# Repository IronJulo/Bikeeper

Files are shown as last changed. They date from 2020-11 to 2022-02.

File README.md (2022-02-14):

# Bikeeper

## What is it? 💡
Bikeeper is a DUT 2 project. The goal of this project is to help bikers to find their motorbike and prevent motocycle stealing. In case off falling or stealing the arduino placed on the motorbike alert his owner. 

## Run 🚀
According to our documentation your can start this project by multiples ways.
### Manually 
You can manually start the Flask website. But we use docker for our database (MariaDB), openstreepmap tiles server, ngnix reverse proxy, grafana. All of this services can be started by executing some small script. 
For exemple : in docker folder run  `sh mariadb.sh` to install mariadb. 
All docker scripts look likes to this : 

```shell
docker run \
  --name bikeeperdb \
  -e=MYSQL_USER=teambikeeper \
  -e=MYSQL_PASSWORD=bikeeper \
  -e=MARIADB_RANDOM_ROOT_PASSWORD=no \
  -e=MYSQL_ROOT_PASSWORD=bikeepersu \
  -p 3306:3306 \
  -d mariadb/server:10.3 \
  --log-bin \
  --binlog-format=MIXED 
```
|Name | Script |Comments|
|--|--|--|
| MariaDB | docker/mariadb.sh | Simple Mariadb server to store flask website data.  |
| Grafana | docker/grafana/grafana.sh | Need few additionals steps: run `grafana-pluging.sh` to install plugings|
|TileServerGL|docker/openstreetmap/osm-server.sh||
|Ngnix|docker/ngnix/ngnix.sh|Reverse proxy to allow flask and grafana to iframe a chart (CORS issues)|

### Docker 🐳
Install docker and docker compose with `docker-setup.sh` script.
After run `docker-compose up` to start the project. 

## Documentation 📄 : 

To see our project documentation clone this repo and run  `docsify serve docs` or open [page](https://ironjulo.gitlab.io/project-bikeeper/#/)
We use [docsify](https://docsify.js.org/#/) to write this documentation. 
GitLab page : `https://ironjulo.gitlab.io/project-bikeeper/#/`

API is documented, in **docs** folder open `api-documentation.pdf`

## Screenshots 📸 





 
## 👷 Authors  :
| Name | Email|
|--|--|
| **Andrew Mary Huet de Barochez** | andrew.mary-huet-de-barochez@etu.univ-orleans.fr |
| **Jules Brossier** | jules.brss@gmail.com |
| **Xavier Lemaire**| xavier.lemaire@etu.univ-orleans.fr |
| **Kevin Talland**| kevin.talland@etu.univ-orleans.fr |
| **Dorian Hardy**|  [@thegostisdead]( https://github.com/thegostisdead ) |
| **Nicolas Pasquet**| nicolas.pasquet@etu.univ-orleans.fr |
| **Fabien Billauld**| fabien.billault@etu.univ-orleans.fr |
| **Mathieu Ramel**| mathieu.ramel@etu.univ-orleans.fr |

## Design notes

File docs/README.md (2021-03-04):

# Bikeeper

> Bikeeper is a project created at the IUT d'Orléans by 2nd year students

## Goals 

Bikeeper allows people with motorcycles to track their motorbike.     
When a user park his motorbike, bikeeper check the current GPS position of the device and send an alert to the user if a vibration or a suspicious behaviour is detected. 

## Doc

This documentation is not a user manual. This is a technical doc.

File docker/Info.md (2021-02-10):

# Info 

https://grafana.com/tutorials/run-grafana-behind-a-proxy/#1
https://grafana.com/docs/grafana/latest/administration/configure-docker/
https://stackoverflow.com/questions/47405597/x-frame-options-in-nginx-to-allow-all-domains
https://stackoverflow.com/questions/33111835/how-to-set-up-grafana-so-that-no-password-is-necessary-to-view-dashboards

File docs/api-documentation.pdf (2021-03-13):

# Bikeeper API

# Overview

Bikeeper API.

# Version information

Version : 1.0.0

# URI scheme

Host : bikeeperwebsite.com BasePath : /
Schemes : HTTP

# Paths

# Adds bikeeper to the database

POST /api/bikeeper/add/

### Description

This adds a new bikeeper device to the database.

### Responses

HTTP Code | Description | Schema
200 | OK | No Content

### Produces

- application/json

# Adds raw bikeeper to the database

POST /api/bikeeper/add_raw/

### Description

This adds a bikeeper with raw parameters to the database.

### Responses

HTTP Code | Description | Schema
200 | OK | No Content

### Produces

- application/json

# Gets current user contacts

GET /api/bikeeper/contacts/<string:device_id>/

### Description

This gets current user contacts from ORM and returns it.

### Responses

HTTP Code | Description | Schema
200 | OK | No Content

### Produces

- application/json

# Gets current user associated phone

GET /api/bikeeper/currentphone/<string:device_id>/

### Description

This gets the current user phone associated on the database from ORM and returns it.

### Responses

HTTP Code | Description | Schema
200 | OK | No Content

### Produces

- application/json

# Get current user picture stored in database

GET /api/bikeeper/get_battery_level/<string:device_id>

### Description

Get current user picture stored in database

### Responses

HTTP Code | Description | Schema
200 | OK | No Content

### Produces

- application/json

# Gets the device name of a given device

GET /api/bikeeper/get_bikeer_name_by_id/<string:device_id>

### Description

Gets the device name of a given device

### Responses

HTTP Code | Description | Schema
200 | OK | No Content

### Produces

- application/json

# Get last log that gives the location

GET /api/bikeeper/get_last_log_position/<string:device_id>

### Description

Get last log that gives the location

### Responses

HTTP Code | Description | Schema
200 | OK | No Content

### Produces

- application/json
Gets the user’s bikeepers that has logs at a given date.

GET /api/bikeeper/get_last_ride_bikeeper/<string:device_id>

### Description

Gets the user’s bikeepers that has logs at a given date.

### Responses

HTTP Code | Description | Schema
200 | OK | No Content

### Produces

- application/json

# Get logs corresponding to a date

GET /api/bikeeper/get_logs_at_date/<string:device_id>/<string:date>

### Description

Get logs corresponding to a date

### Responses

HTTP Code | Description | Schema
200 | OK | No Content

### Produces

- application/json

# Gets rides by user and selected date

GET /api/bikeeper/get_rides_bikeeper_from_user_at_time/<string:username>/<string:date>

### Description

Gets rides by user and selected date

### Responses

HTTP Code | Description | Schema
200 | OK | No Content

### Produces

- application/json
Gets a list of rides at a given date, bikeeper and user.

GET
/api/bikeeper/get_rides_from_user_at_time_with_bikeeper/<string:username>/<string:devi ce_id>/<string:date>

### Description

Gets a list of rides at a given date, bikeeper and user.

### Responses

HTTP Code | Description | Schema
200 | OK | No Content

### Produces

- application/json

# Gets bikeeper’s owner number

GET /api/bikeeper/get_user_num/<string:device_id>/

### Description

This gets the number of the bikeeper’s owner and returns it.

### Responses

HTTP Code | Description | Schema
200 | OK | No Content

### Produces

- application/json

# Removes selected device

DELETE /api/bikeeper/remove/<int:device_id>/

### Description

This removes the current device from the database using ORM function.

### Responses

HTTP Code | Description | Schema
200 | OK | No Content

### Produces

- application/json

# Get user research

GET /api/bikeeper/search_user/

### Description

Find user in database

### Responses

HTTP Code | Description | Schema
200 | OK | No Content

### Produces

- application/json

# Update current device settings to the database

POST /api/bikeeper/settings/<string:device_id>/update/

### Description

This updates settings of the device on the database using ORM function.

### Responses

HTTP Code | Description | Schema
200 | OK | No Content

### Produces

- application/json

# Get current contact picture stored in database

GET /api/contact/profile/<string:contact_id>

### Description

Get current contact picture stored in database

### Responses

HTTP Code | Description | Schema
200 | OK | No Content

### Produces

- application/json

# Get the current selected device stored in database

GET /api/current_device/<string:username>

### Description

Get the current selected device stored in database

### Responses

HTTP Code | Description | Schema
200 | OK | No Content

### Produces

- application/json

# Update the current selected device stored in database

GET /api/device/<int:id_device>

### Description

Update the current selected device stored in database

### Responses

HTTP Code | Description | Schema
200 | OK | No Content

### Produces

- application/json
This sends a SMS to the database.

POST /api/sms/add/

### Description

Sends sms to the bd

### Responses

HTTP Code | Description | Schema
200 | OK | No Content

### Produces

- application/json

# Gets current cpu usage

GET /api/stats/cpu/

### Description

This gets current cpu usage of the server.

### Responses

HTTP Code | Description | Schema
200 | OK | No Content

### Produces

- application/json

# Gets current ram usage

GET /api/stats/ram/

### Description

This gets current ram usage of the server.

### Responses

HTTP Code | Description | Schema
200 | OK | No Content

### Produces

- application/json

# Update the current selected device stored in database

POST /api/test/update_device/<string:username>/<int:id_device>

### Description

Update the current selected device stored in database

### Responses

HTTP Code | Description | Schema
200 | OK | No Content

### Produces

- application/json

# Get current user picture stored in database

GET /api/user/profile/<string:username>

### Description

Get current user picture stored in database

### Responses

HTTP Code | Description | Schema
200 | OK | No Content

### Produces

- application/json

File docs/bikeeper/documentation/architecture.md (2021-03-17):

# Architecture

>Global Arch

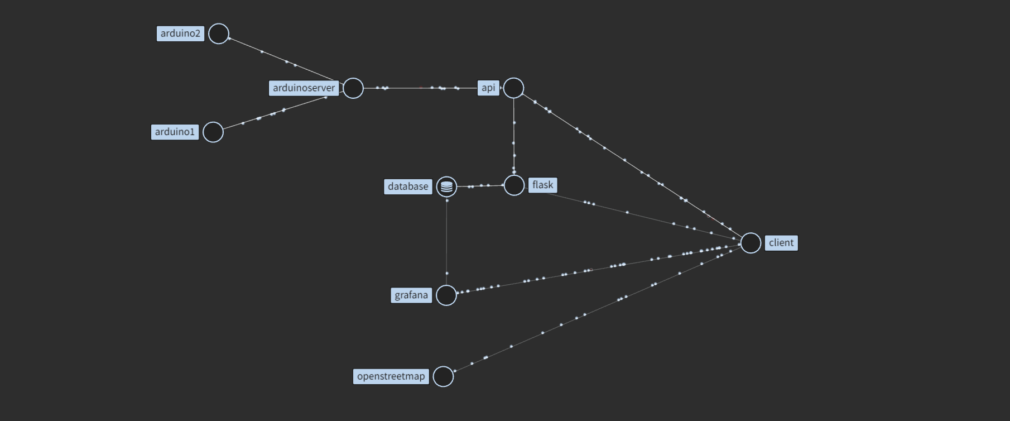
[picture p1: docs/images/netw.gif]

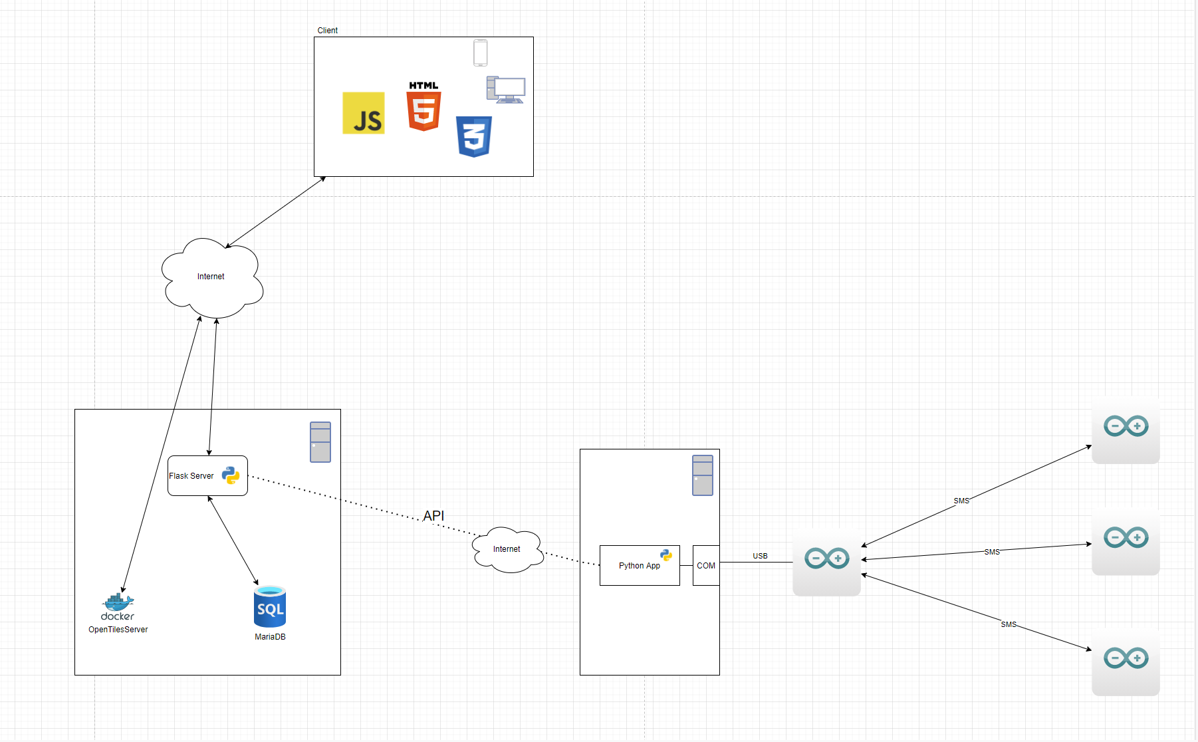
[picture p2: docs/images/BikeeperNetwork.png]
Bikeeper networks
    

>Website

Bikeeper website folders are organized in this way : 

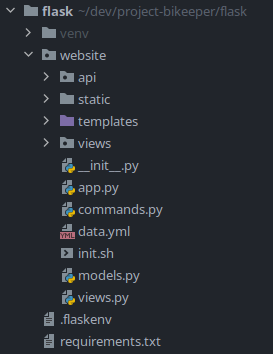
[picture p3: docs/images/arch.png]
Bikeeper arch


| Folder | What's inside ? | 
| --- |---|
| **api** |api to interact with bikeeper sms server using REST API |
| **static** | All assets files (images,css,js) |
|**templates** |All templates are inside. Bikeeper use 2 types of templates, mobile template and pc template.|
|**views** |All the views are bind to routes.|

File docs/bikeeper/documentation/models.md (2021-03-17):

# Models

> Database

We create this tables representation

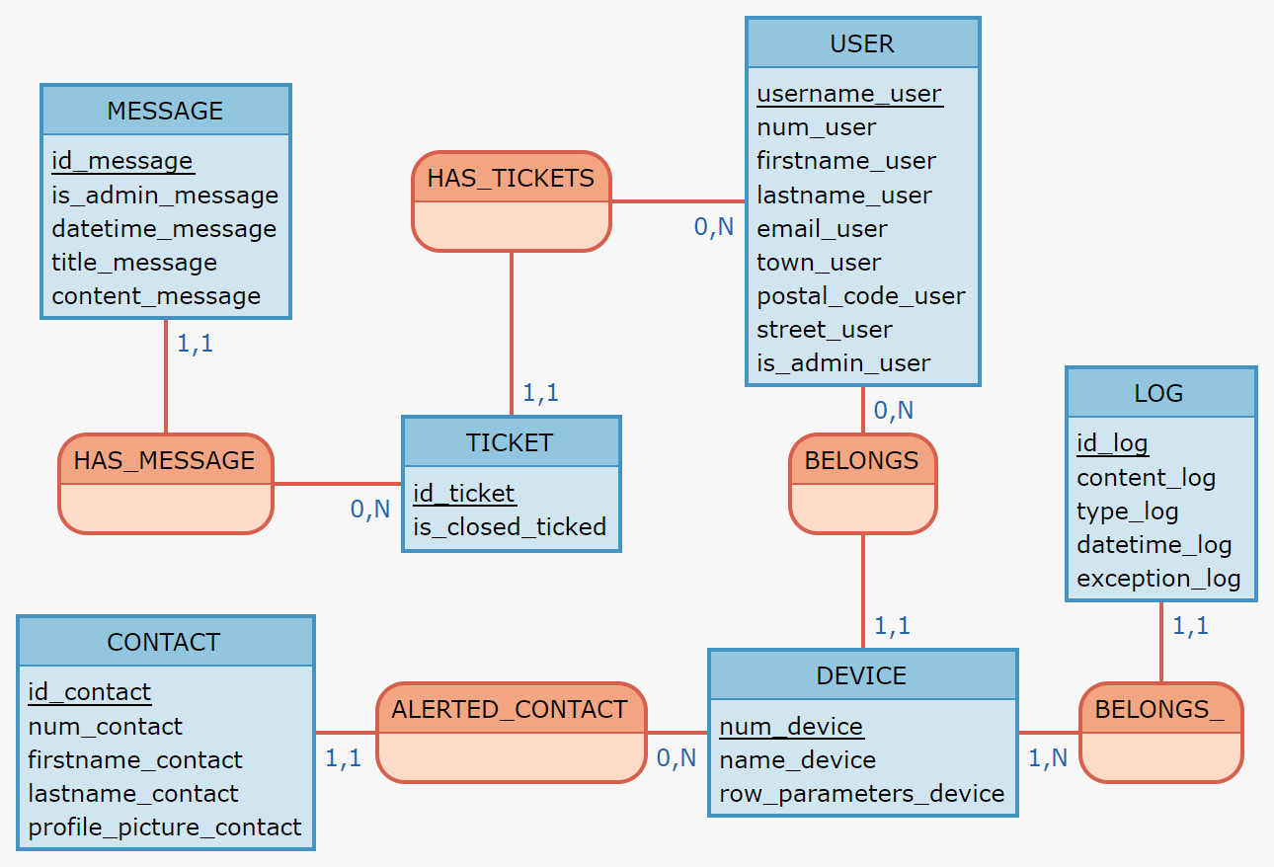
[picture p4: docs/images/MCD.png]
Bikeeper networks


---

> ORM

?> **Tip** To interact with our database we use [sqlalchemy](https://www.sqlalchemy.org/). 

Sqlalchemy provide a easy to use query system and a fast sql table creation. 

To call our database `app.py`
```python
app.config['SQLALCHEMY_DATABASE_URI'] = 'mysql+pymysql://{}:{}@{}/BIKEEPER'.format(os.environ.get('SERVER_USER'),os.environ.get('SERVER_PASSWORD'), os.environ.get('SERVER_IP'))

# Module that will build python objects
db = SQLAlchemy(app)

# Engine connecting to MariaDB
engine = sqlalchemy.create_engine(app.config['SQLALCHEMY_DATABASE_URI'], echo=False)  # , isolation_level="READ  

```

--- 

All tables are represented like this. 

```python 
class LOG(db.Model):
    """
    Store all activities generated by Bikeepers like Alerts, Moving etc...
    """
    id_log = db.Column(db.Integer, primary_key=True, autoincrement=True)
    content_log = db.Column(db.String(150))
    type_log = db.Column(db.String(20))
    datetime_log = db.Column(DateTime())
    exception_log = db.Column(db.String(160))
    num_device = db.Column(db.String(15), db.ForeignKey("DEVICE.num_device"))
    DEVICE = db.relationship("DEVICE", backref=db.backref("LOG", lazy="dynamic"))

    def __init__(self, content_log, type_log, datetime_log, exception_log, num_device):
        self.content_log = content_log
        self.type_log = type_log
        self.datetime_log = datetime_log
        self.exception_log = exception_log
        self.num_device = num_device

    def serialize(self):
        return {
            "id_log": self.id_log,
            "content_log": self.content_log,
            "type_log": self.type_log,
            "datetime_log": self.datetime_log,
            "exception_log": self.exception_log,
            "num_device": self.num_device
        }

```

?> **Tip** `serialize` method allow us to print directly the object. 

--- 

To make queries, we defined functions that return an Object defined in model class.

```python 
@staticmethod
    def get_last_message_by_ticket_id(ticket_id):
        """
        return: last message of the tickets
        """
        dict_message = ORM.get_message_by_ticket_id(ticket_id)
        if not dict_message:
            return {}
        return dict_message[max(dict_message.keys())]

    @staticmethod
    def messages_to_json(messages):
        """
        Turn the given messages into a json form
        """
        return jsonify(messages)

    @staticmethod
    def get_open_ticket():
        """
        :return: opened tickets,
        """
        res = session.query(TICKET).filter(TICKET.is_closed_ticket == 0).all()
        db.session.commit()
        return res
```

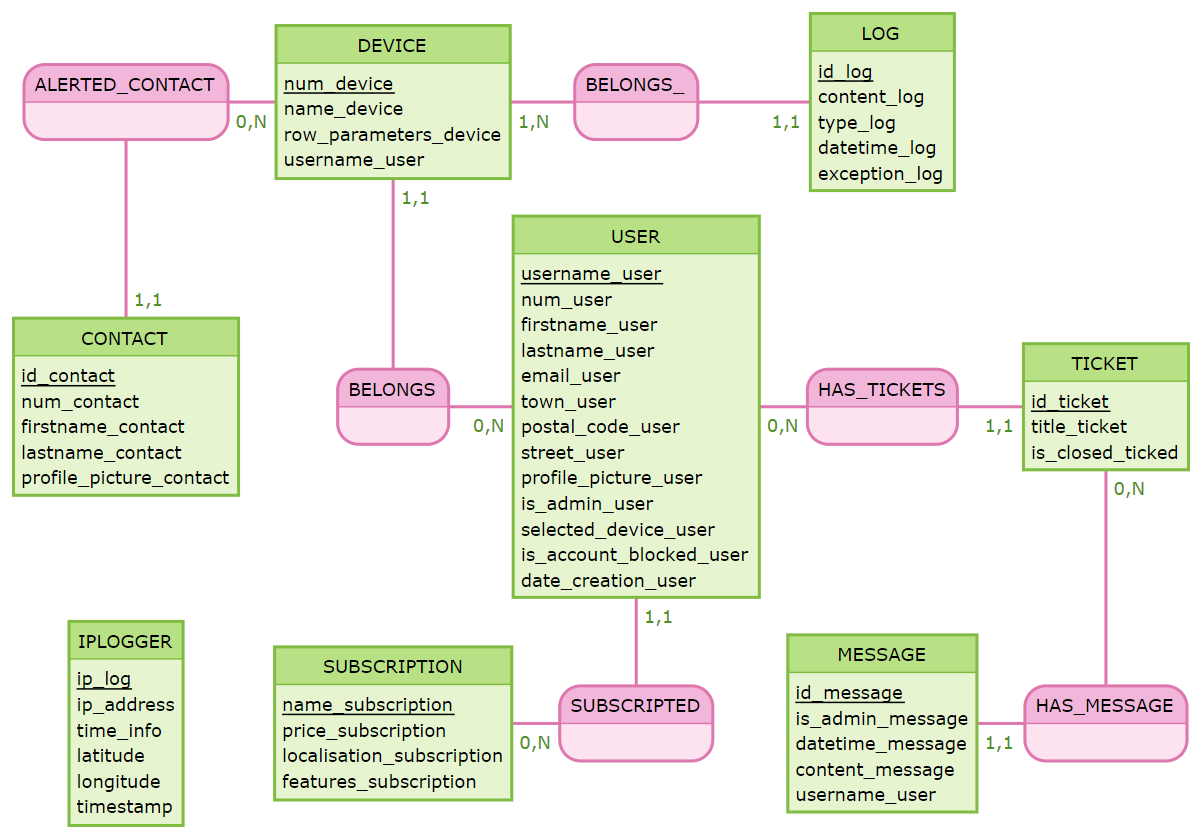
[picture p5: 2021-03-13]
bd/MCD.png

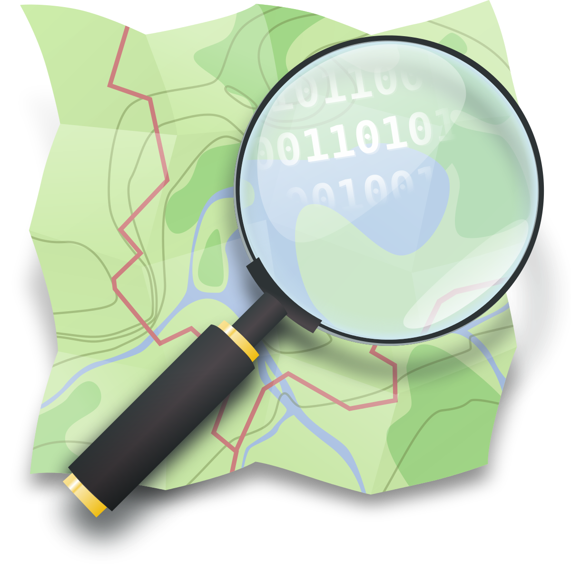
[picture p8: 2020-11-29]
flask/website/static/pc/assets/localisation-1.png

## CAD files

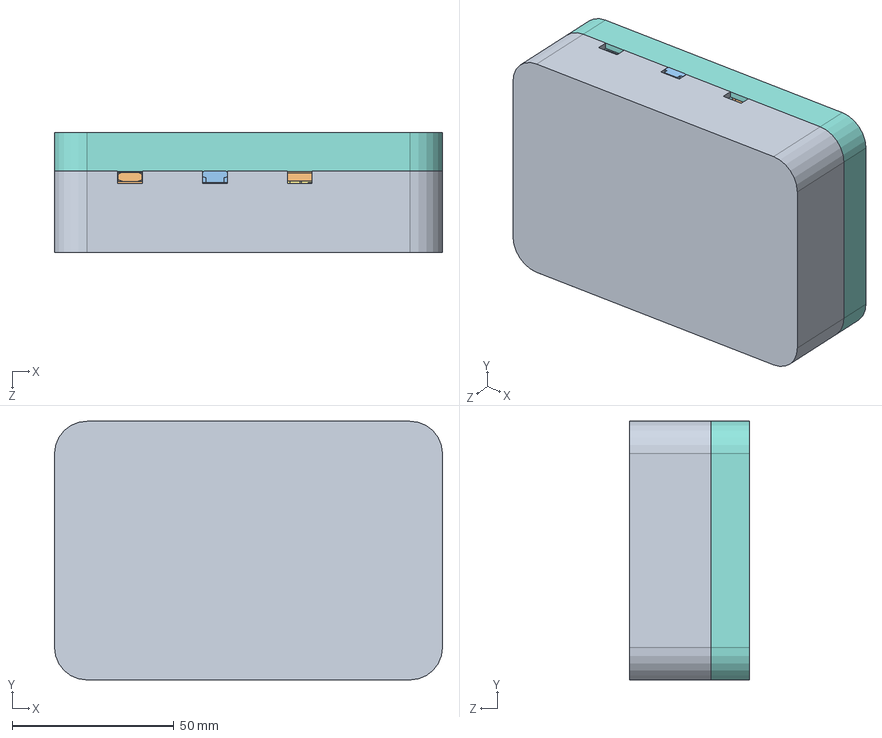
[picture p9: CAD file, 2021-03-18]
3D_Models/Build_Complete.SLDASM
120.0 x 80.0 x 37.1 mm
Pcb
Support_6x x 4
Support_15x x 2
Support_4x
Support_8x
Support_5x
Support_7x
Connector_2x x 2
Box_Bottom
Chargeur_Li-ion x 2
Arduino_Nano
Batterie
Tilt_Sensor
GPS
SIM_800L
Box_top

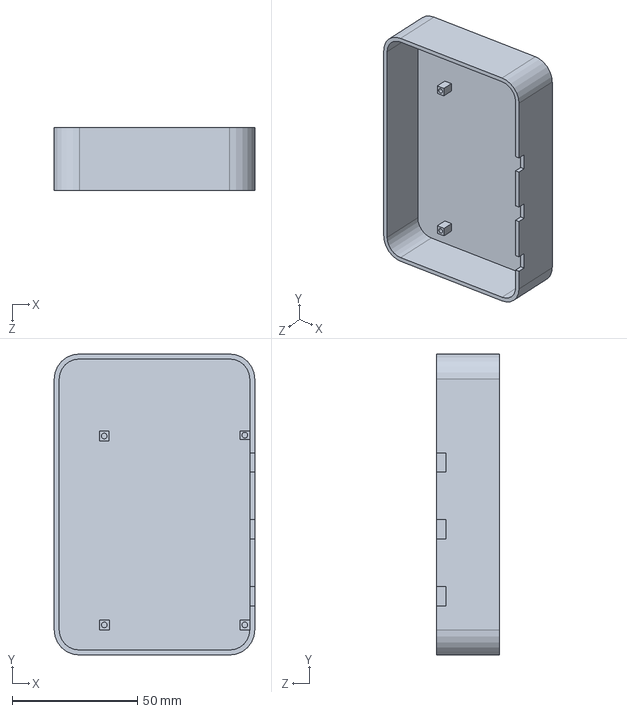
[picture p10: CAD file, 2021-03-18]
3D_Models/Complete_Build.SLDASM
80.0 x 120.0 x 25.2 mm

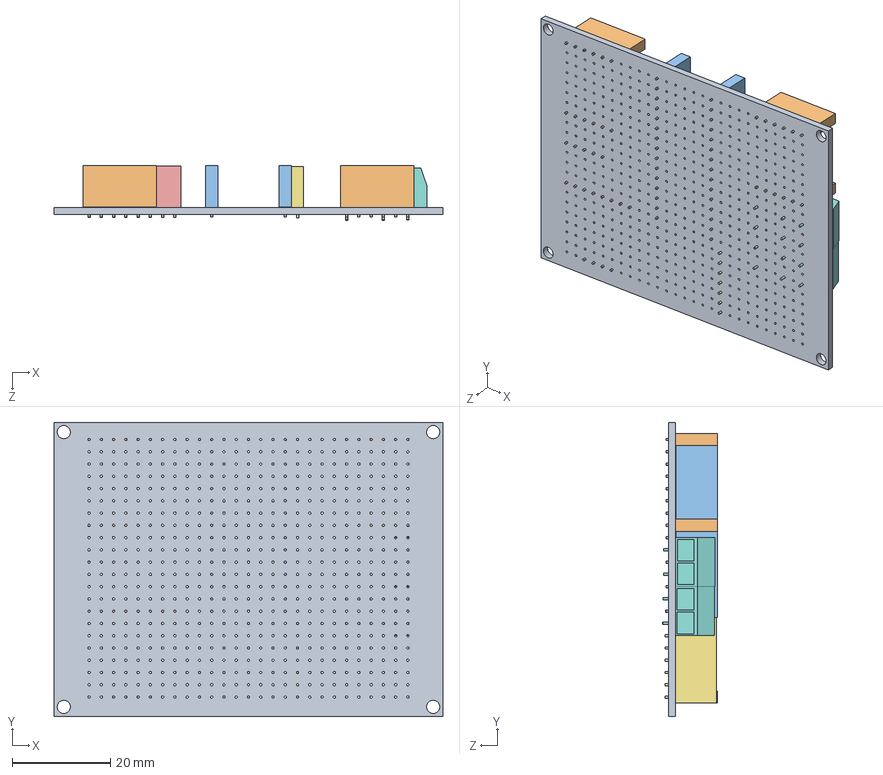
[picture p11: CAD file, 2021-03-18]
3D_Models/Build.SLDASM
79.3 x 60.0 x 11.2 mm
Pcb
Support_6x x 4
Support_15x x 2
Support_4x
Support_8x
Support_5x
Support_7x
Connector_2x x 2
Resistor x 4

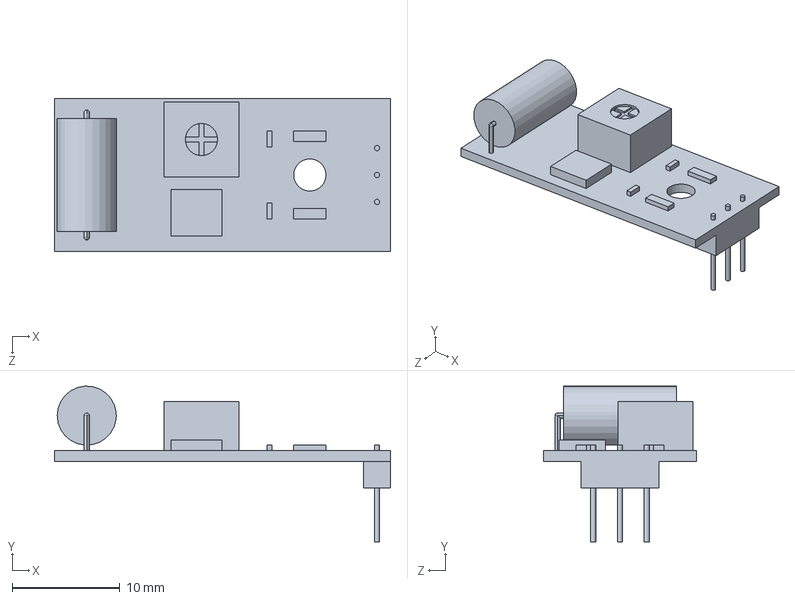
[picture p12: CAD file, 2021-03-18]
3D_Models/Vibration_detector.SLDPRT
31.2 x 14.5 x 14.2 mm

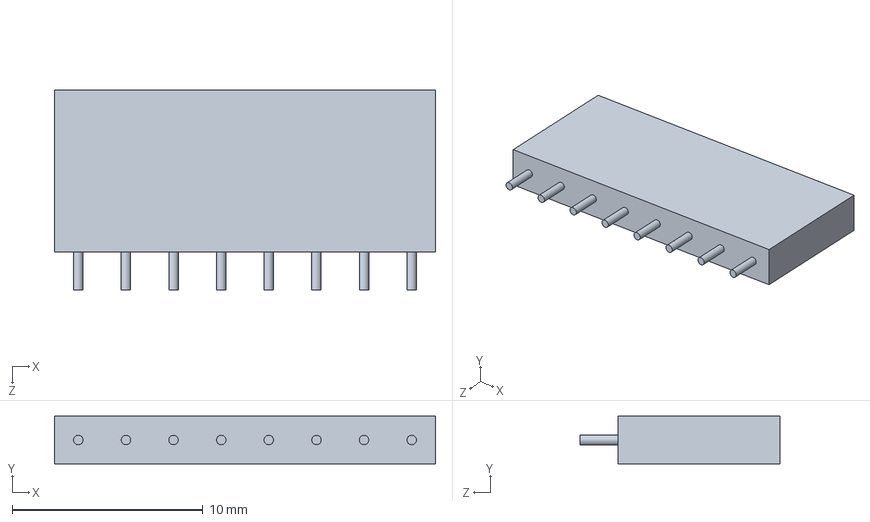
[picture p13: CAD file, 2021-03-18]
3D_Models/Support_8x.SLDPRT
20.0 x 2.50 x 10.5 mm

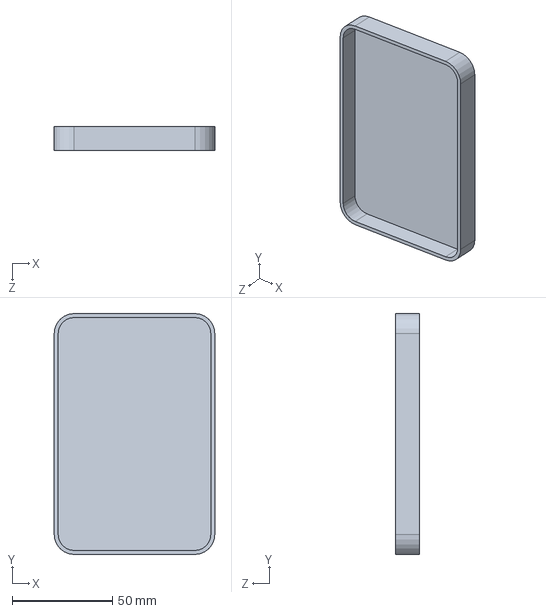
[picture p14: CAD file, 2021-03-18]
3D_Models/Box_top.SLDPRT
80.0 x 120.0 x 12.0 mm

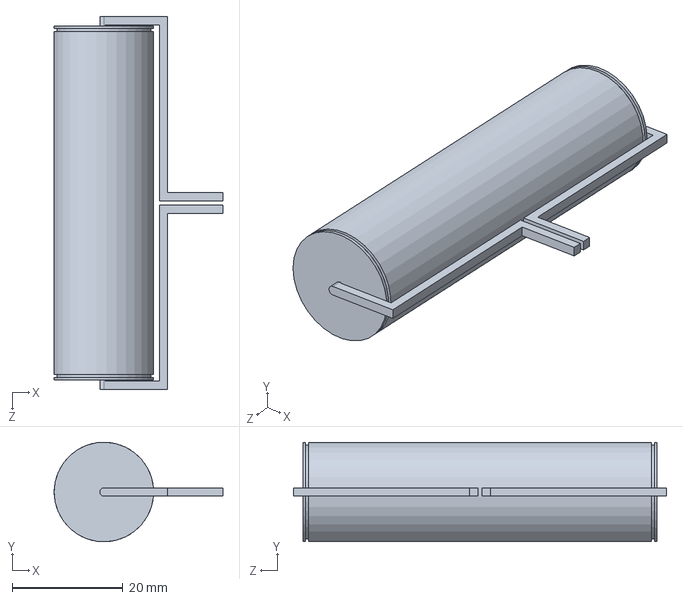
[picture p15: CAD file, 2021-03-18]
3D_Models/Batterie.SLDPRT
30.5 x 18.0 x 67.4 mm

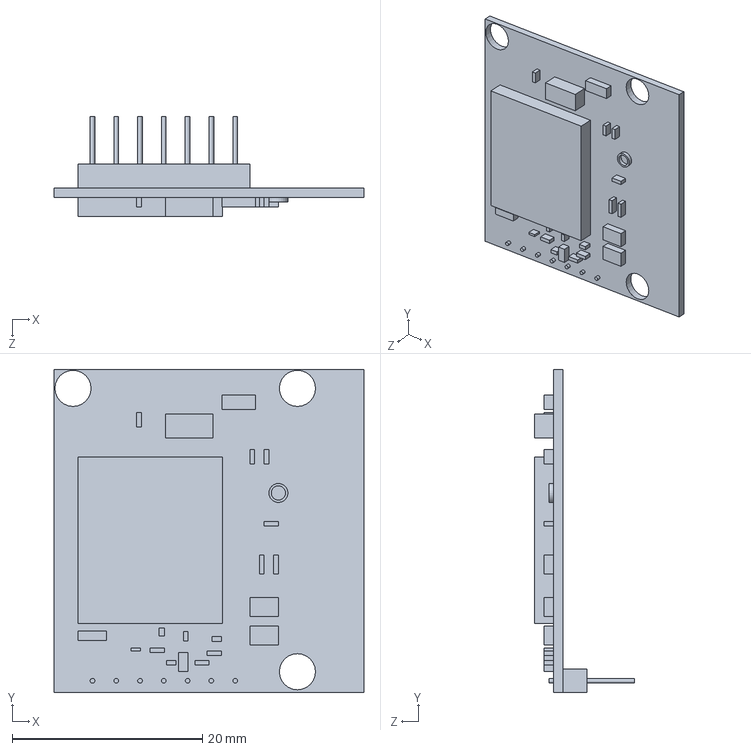
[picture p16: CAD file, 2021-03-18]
3D_Models/SIM_800L.SLDPRT
32.6 x 34.0 x 10.5 mm

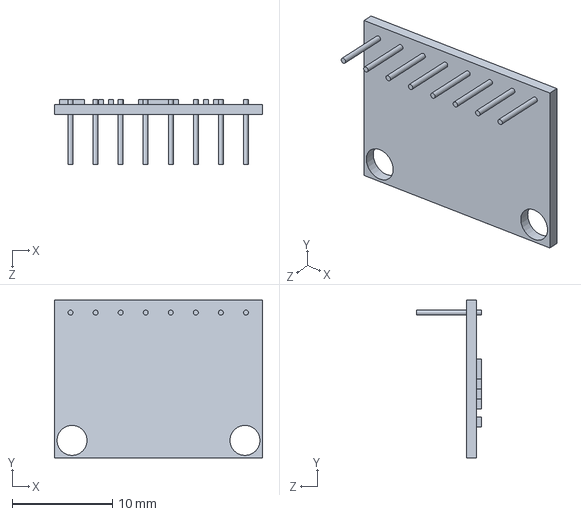
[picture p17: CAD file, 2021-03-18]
3D_Models/Tilt_Sensor.SLDPRT
20.8 x 15.8 x 6.50 mm

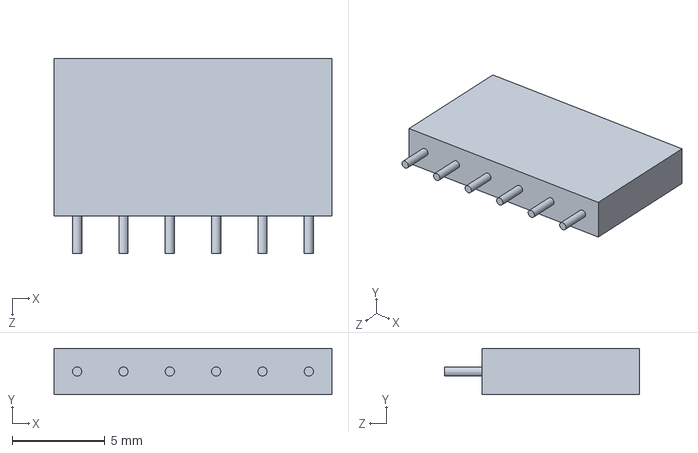
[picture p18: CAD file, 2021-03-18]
3D_Models/Support_6x.SLDPRT
15.0 x 2.50 x 10.5 mm

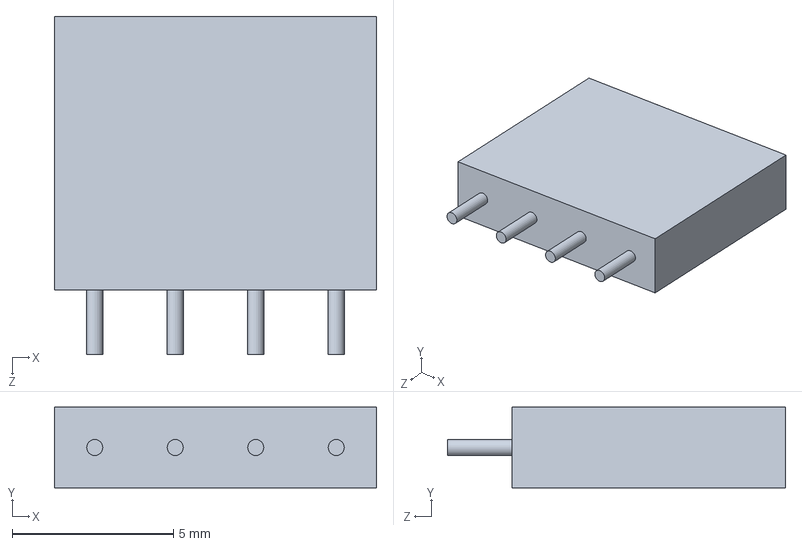
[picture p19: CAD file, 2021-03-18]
3D_Models/Support_4x.SLDPRT
10.0 x 2.50 x 10.5 mm

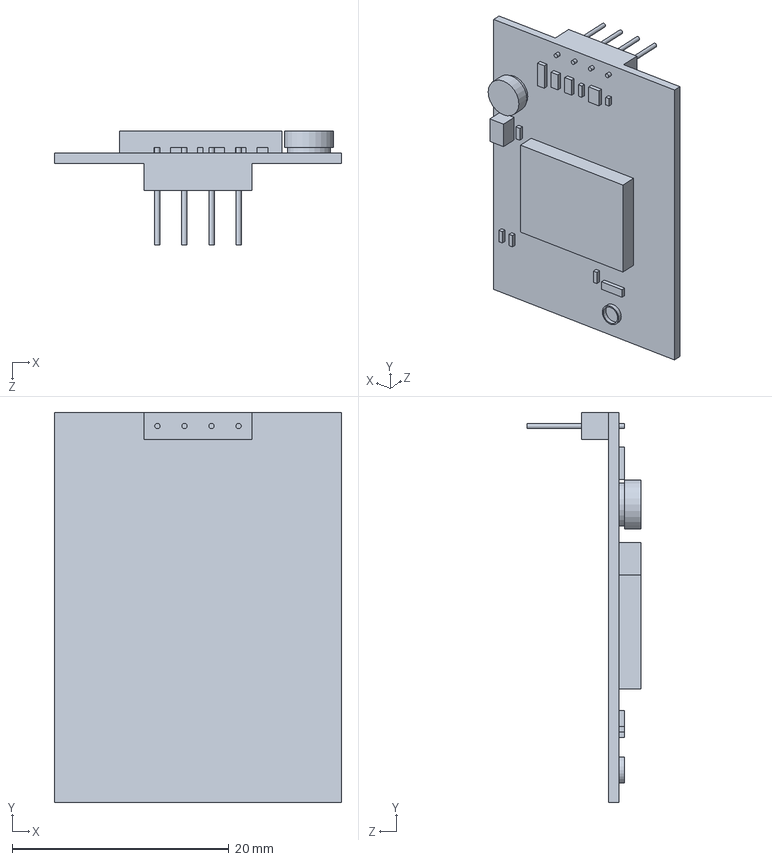
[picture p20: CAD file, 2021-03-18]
3D_Models/GPS.SLDPRT
26.5 x 36.0 x 10.5 mm

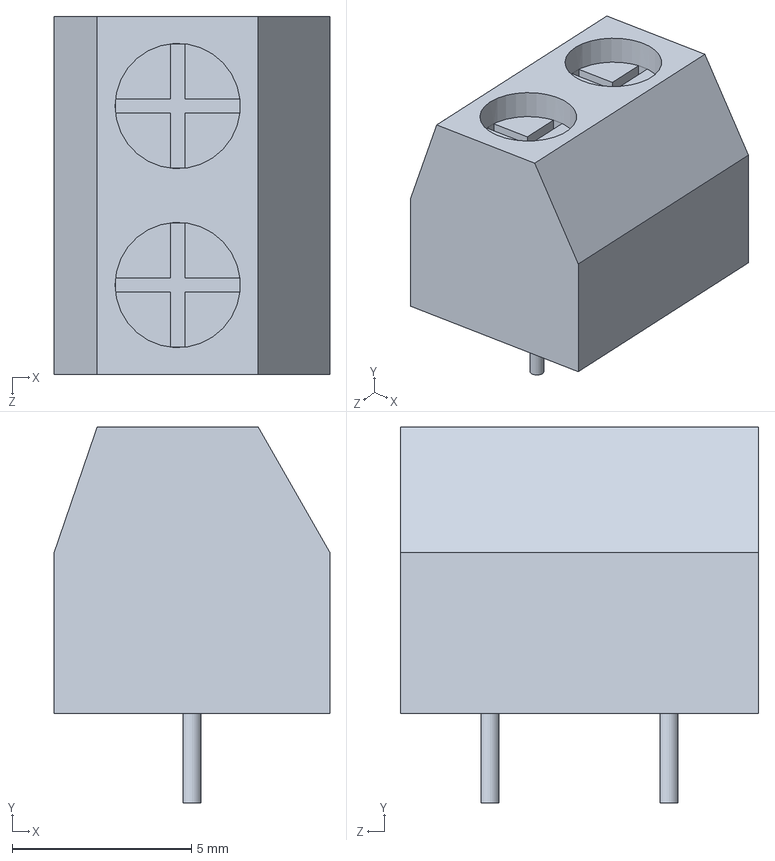
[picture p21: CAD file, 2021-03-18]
3D_Models/Connector_2x.SLDPRT
7.70 x 10.5 x 10.0 mm

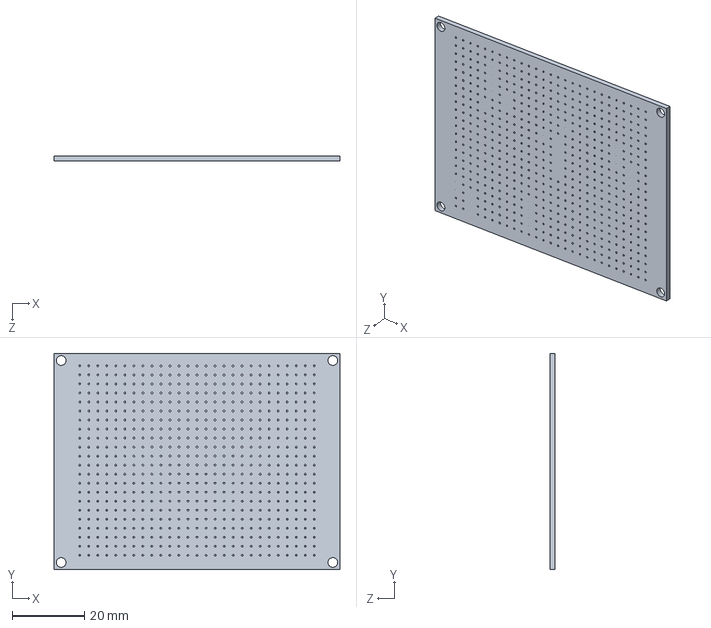
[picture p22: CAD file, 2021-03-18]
3D_Models/Pcb.SLDPRT
79.3 x 60.0 x 1.50 mm

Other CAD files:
3D_Models/Box_Bottom.SLDPRT
3D_Models/Support_7x.SLDPRT
3D_Models/Arduino_Nano.SLDPRT
3D_Models/Support_5x.SLDPRT
3D_Models/Build_Complete - Copie.SLDASM
3D_Models/Chargeur_Li-ion.SLDPRT
3D_Models/Resistor.SLDPRT
3D_Models/Support_15x.SLDPRT

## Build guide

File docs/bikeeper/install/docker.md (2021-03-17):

# Docker 

## How to start ?    

To run all services clone the repo and run `docker-compose up` .     
To stop the services type `docker-compose down` or press `ctrl+c` if your terminal is atteched to docker-compose.

## How it works ?  

Docker-compose will automatically deploy the bikeeper platform.     
It start : 
- mariadb
- grafana 
- ngnix
- flask
- openstreetmap

!> **Important** Please, replace the osm token by a new one. The token is available for one hour.  [Token](https://data.maptiler.com/downloads/tileset/osm/europe/france/centre/?wizard).   

```yaml
version: '3'
services:
  db:
    image: mariadb/server:10.3
    container_name: bikeeperbd
    expose:
      - 3306
    ports:
    - 3306:3306
    command:
      --log-bin
      --binlog-format=MIXED
    environment:
      - MYSQL_USER=teambikeeper
      - MYSQL_PASSWORD=bikeeper
      - MARIADB_RANDOM_ROOT_PASSWORD=no
      - MYSQL_ROOT_PASSWORD=bikeepersu
      - MYSQL_DATABASE=BIKEEPER
    healthcheck:
      test: "/usr/bin/mysql --user=teambikeeper --password=bikeeper --execute \"SHOW DATABASES;\""
      interval: 2s
      timeout: 20s
      retries: 10

  bikeeper-website:
    container_name: bikeeper
    depends_on:
      db:
        condition: service_healthy
    build: ./flask/
    volumes:
      - ./flask/:/usr/src/app/
    ports:
      - 8080:8080
    environment:
      PORT: 8080
      HOST: 0.0.0.0
      FLASK_DEBUG: 1

  osm:
    image: osm-bundle
    container_name: osm
    build:
      context: .
      dockerfile: ./docker/openstreetmap/osm.Dockerfile
      args:
        - MAP_TOKEN=WyJiZmZkZmM5NS1lMTVlLTRmYjgtYWFkZC1lNzM5MGQ1NjAxOTciLCItMSIsODcwMl0.YD6sPw.MEJHhB0BwjOEbCH95mX5o305m3s # get a new on here https://data.maptiler.com/downloads/tileset/osm/europe/france/centre/?wizard
    depends_on:
      db:
        condition: service_healthy
#    volumes:
#      - ./docker/openstreetmap/:/data
    ports:
      - 8989:80
    command:
      --bind 0.0.0.0
      --mbtiles /bundle/centre.mbtiles

  reverse-proxy:
    image: nginx
    container_name: nginxreverse
    depends_on:
      - grafana
      - bikeeper-website
    volumes:
      - ./docker/ngnix/nginx.conf:/etc/nginx/nginx.conf
    ports:
      - 80:80

  grafana:
    image: grafana/grafana
    container_name: grafana
    depends_on:
      - db
    environment:
      - "GF_INSTALL_PLUGINS=grafana-worldmap-panel"
      - "GF_INSTALL_IMAGE_RENDERER_PLUGIN=true"
      - "GF_DATABASE_TYPE=mysql"
      - "GF_DATABASE_NAME=BIKEEPER"
      - "GF_DATABASE_USER=teambikeeper"
      - "GF_DATABASE_HOST=db"
      - "GF_DATABASE_PASSWORD=bikeeper"
      - "GF_ANALYTICS_REPORTING_ENABLED=false"
      - "GF_SECURITY_ADMIN_USER=admin"
      - "GF_SECURITY_ADMIN_PASSWORD:=admin"
    volumes:
      - ./docker/grafana/grafana.ini:/etc/grafana/grafana.ini
      - ./docker/grafana/grafana-storage:/var/lib/grafana
    ports:
      - 3000:3000

```

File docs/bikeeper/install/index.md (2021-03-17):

# Installation 

?> **Tip** There is 2 ways to install Bikeeper. 

## By hands 

!> **Important** If you choose this method you need to install by our own **MariaDB, Grafana, Ngnix (reverse proxy for grafana), OpenStreetMap Server Tiles**

?> **Tips** In the project repository in the docker folder some shell scripts can help you to install all required services.

## With docker  

You can use our docker-compose file. 

?> **Tips**  This script will install docker and docker-compose. Run it with sudo. Tested on ubuntu ✅ 
```shell
apt update 
apt upgrade -y 
apt install apt-transport-https ca-certificates curl gnupg-agent software-properties-common -y 
curl -fsSL https://download.docker.com/linux/ubuntu/gpg | sudo apt-key add -
add-apt-repository "deb [arch=amd64] https://download.docker.com/linux/ubuntu $(lsb_release -cs) stable"
apt get update
apt get install docker-ce docker-ce-cli containerd.io -y 
usermod -aG docker $USER
# install docker compose after
curl -L "https://github.com/docker/compose/releases/download/1.28.4/docker-compose-$(uname -s)-$(uname -m)" -o /usr/local/bin/docker-compose
chmod +x /usr/local/bin/docker-compose
```

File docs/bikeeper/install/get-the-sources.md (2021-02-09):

# Get the sources

To get sources clone the last version of [Bikeeper repository](https://gitlab.com/IronJulo/project-bikeeper) 

```bash
git clone https://gitlab.com/IronJulo/project-bikeeper    

cd project-bikeeper
```

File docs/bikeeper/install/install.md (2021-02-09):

# Install & dependency

This project use many librairies. Bikeeper use virtualenv. 
Open project folder 

```bash
cd project-bikeeper/flask
```

Create python virtual env to install pip modules. 

```bash
python -m venv venv 
source venv/bin/activate
pip install -r requirements.txt
```

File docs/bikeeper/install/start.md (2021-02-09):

# Start !

```bash
cd project-bikeeper/flask/website    
flask run --host="0.0.0.0"
```

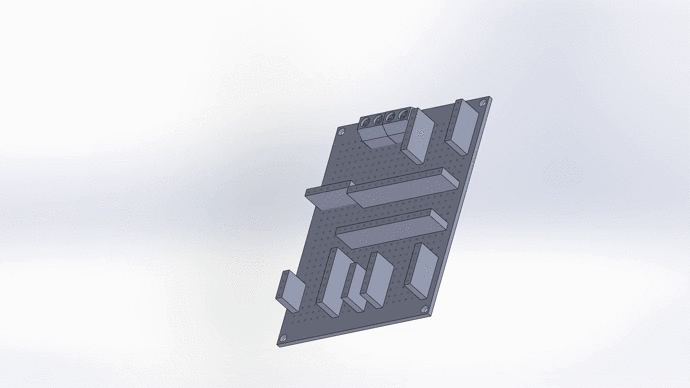
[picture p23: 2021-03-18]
3D_Models/Build_Complete5.gif

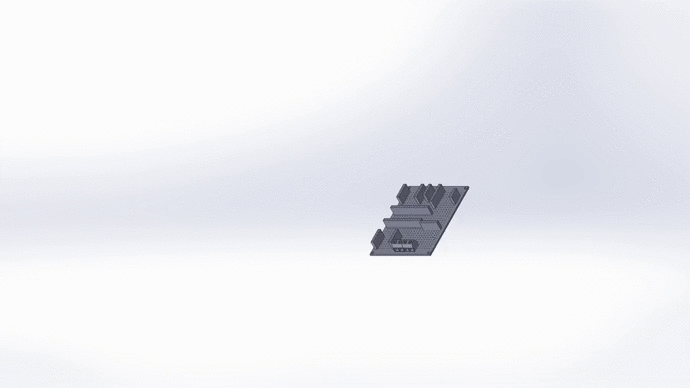
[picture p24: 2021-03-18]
3D_Models/Build_Complete4 (1).gif

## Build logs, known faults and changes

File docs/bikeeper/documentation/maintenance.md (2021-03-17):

# Maintenance

Maintain is very easy, just update ! 

To maintain bikeeper : 
- update your linux (`apt update -y && apt upgrade -y`)
- update docker image to lasted
- inspect logs (`docker logs container_name`)
- monitor your disk free space `df -h /` and `df -h | awk '{print $5 " " $6}' | sort -n | tail -5`
- Clean log ```for I in `ls "/var/log/*.log"`;do >"$I";done```
- Check internet connectivity `ping 8.8.8.8`
- Inspect Process performances `htop`   
If you have any issues email a Bikeeper developpers.

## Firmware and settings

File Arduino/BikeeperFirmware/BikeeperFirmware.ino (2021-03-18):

/*
for the arduino uno
                                             ╔═══╗                   ╔═════╗
                                        ╔════╣PWR╠═══════════════════╣ USB ╠══╗
                                        ║    ╚═══╝                   ╚═════╝  ║
                                        ║         GND/RST2  [ ][ ]            ║
                                        ║       MOSI2/SCK2  [ ][ ]  A5/SCL[ ] ║ 
                                        ║          5V/MISO2 [ ][ ]  A4/SDA[ ] ║
                                        ║                             AREF[ ] ║
                                        ║                              GND[ ] ║
                                        ║ [ ]N/C                    SCK/13[ ] ║
                                        ║ [ ]IOREF                 MISO/12[ ] ║
                                        ║ [ ]RESET                 MOSI/11[ ]~║
                                        ║ [ ]3V3    ╔═══╗               10[ ]~║
  +5V (2A) external power supply <══════║ [ ]5v    ═╣ A ╠═               9[ ]~║
    Ground external power supply <══════║ [ ]GND   ═╣ R ╠═               8[ ] ║══════> SIM800L rx 
                                        ║ [ ]GND   ═╣ D ╠═                    ║
                                        ║ [ ]Vin   ═╣ U ╠═               7[ ] ║══════> SIM800L tx
                                        ║          ═╣ I ╠═               6[ ]~║
                                        ║ [ ]A0    ═╣ N ╠═               5[ ]~║
                                        ║ [ ]A1    ═╣ O ╠═               4[ ] ║══════> GPS tx
                    Bike battery <══════║ [ ]A2     ╚═══╝           INT1/3[ ]~║
                  Device battery <══════║ [ ]A3                     INT0/2[ ] ║══════> Interrupt pin for the "do" pin of the vibration sensor
                   Gyroscope SDA <══════║ [ ]A4/SDA  RST SCK MISO     TX>1[ ] ║
                   Gyroscope SCL <══════║ [ ]A5/SCL  [ ] [ ] [ ]      RX<0[ ] ║
                                        ║            [ ] [ ] [ ]              ║
                                        ║            GND MOSI 5V ╔════════════╝
                                        ╚═══UNO_R3═══════════════╝ 
*/

#include <Arduino.h>
#include <TinyGPS++.h>
#include <SoftwareSerial.h> // for Sim800L & Tinygps++
#include <string.h>
#include "Wire.h"

#include "I_Sim800L.hpp"
#include "StringBuffer.hpp"
#include "StringsSms.hpp"
#include "SmsFormatter.hpp"
#include "Utils.hpp"

/*#include "Headers/messageHeader.h"
#include "Headers/messageAlert.h"
#include "Headers/messageTrajet.h"
#include "Headers/messageHeartbeat.h"
#include "Headers/messageReceived.h"*/
#include "Headers/location.h"

/* Sim800L */
// and +33664277796
#define SERVER_PHONE_NUMBER "+33664277796" // BiKServer number (main server) called to get user number

char userPhoneNumber[13] = "";

#define GSM_BAUDRATE 9600
#define GSM_RX 7
#define GSM_TX 8

SoftwareSerial softwareSim800l(GSM_RX, GSM_TX);

char sms_storage[150];
StringBuffer sms_buffer(sms_storage, sizeof(sms_storage));

char message_storage[80];
StringBuffer message_buffer(message_storage, sizeof(message_storage));
SmsFormatter smsFormatter(&message_buffer); //Not used all the time but to simplify sms generation

I_Sim800L sim800L(&softwareSim800l, &sms_buffer);
/* Sim800L */

/* States */
bool parked = false;
bool journey = false;
/* States */

/* Vibration sensor */
bool vibartion = false; // False most of the time but true if the module detected a vibration (trough interrupt)
#define VIBRATION 'V'
/* Vibration sensor */

/* Battery sensor */
#define DEVICE_BATTERY_PIN A3 // Declare the device battery (analog)
#define BIKE_BATTERY_PIN A2	 // Declare the device battery (analog)

#define deviceMaxBatteryVoltage 1024 //verify later
#define bikeMaxBatteryVoltage 1024 // verify later

double deviceBatteryLevel = 0;
double bikeBatteryLevel = 0;

bool isBatteryCharging = false;
/* Battery sensor */

/* GPS */
#define GPS_RX 4 // Declare the SIM800L onto the pin 7.
#define GPS_TX 3

#define GPS_BAUDRATE 9600
TinyGPSPlus gps;

location_t location; // Declare the Location type
int bikeSpeed = 0;
SoftwareSerial gpsSerial(GPS_RX, GPS_TX);
bool bikeMoved = false;
#define GPS_TRESHOLD_LAT 0.000100 //0.000011
#define GPS_TRESHOLD_LON 0.000100 //0.000020
/* GPS */

/* Angle Detection */
#define GYRO_MIN_MAX_X 16000
#define GYRO_MIN_MAX_Y 17600
#define FALL_CALL_TIMEOUT 60000 // 1 minute
#define ANGLE_TRESHOLD 800 // Max angle before threating it as a fall 

const int MPU_ADDR = 0x68;
bool bikeFallen = false;
double gyro_y, gyro_x;
short zeroGyro_y, zeroGyro_x = 0;
unsigned long fallTime = 0;
/* Angle Detection */



/* heartbeat */
#define HEARTBEAT_TIMEOUT 20000 //time between each heart beat sms
unsigned long lastHeartbeatTime = millis();

/* heartbeat */
void setup()
{
	Serial.begin(9600);
	gpsSerial.begin(GPS_BAUDRATE);
	sim800L.begin(GSM_BAUDRATE);

	sim800L.init(userPhoneNumber, SERVER_PHONE_NUMBER);

	message_buffer.clear();
	strcpy_P(message_buffer.getStorage(), (char *)pgm_read_word(&(string_table[indexStringSyncOk])));

	sim800L.send(userPhoneNumber, message_buffer.getStorage());

	attachInterrupt(0, vibartionDetected, RISING); // Interrupt for the vibration detector (RISING because the detector emmit ~3.5V for 10 ms).

	Serial.println(message_buffer.getStorage());
	message_buffer.clear();
	sim800L.smartRead("+CMGS", 5, 30000);
	sim800L.deleteALL();
	sim800L.setModeTexte();
	sim800L.smartRead("OK", 2, 500);

	Wire.begin();
	Wire.beginTransmission(MPU_ADDR);
	Wire.write(0x6B);
	Wire.write(0);
	Wire.endTransmission(true);

	interrupts();
}

void loop()
{
	actualizeLocation();
	actualizeBatterys();
	actualizeIsBatteryCharging();
	actualizeAngle();
	if (parked)
	{
		//interrupts();
		if (vibartion) /* TODO timeout */
		{
			vibartion = false;
			message_buffer.clear();

			strcpy_P(message_buffer.getStorage(), (char *)pgm_read_word(&(string_table[indexStringVibrationDetected])));
			sim800L.send(userPhoneNumber, message_buffer.getStorage());
			sim800L.smartRead("+CMGS", 5, 1000);
			delay(1500);

			message_buffer.clear();

			smsFormatter.makeAlertSms('W', 'V', &location, isBatteryCharging, deviceBatteryLevel, bikeBatteryLevel);
			sim800L.send(SERVER_PHONE_NUMBER, smsFormatter.getStorage());
			sim800L.smartRead("+CMGS", 5, 1000);

			delay(100);

			message_buffer.clear();
		}

		if (bikeMoved)
		{
			bikeMoved = false;

			message_buffer.clear();

			strcpy_P(message_buffer.getStorage(), (char *)pgm_read_word(&(string_table[indexStringMovementDetected])));
			sim800L.send(userPhoneNumber, message_buffer.getStorage());
			sim800L.smartRead("+CMGS", 5, 1000);
			delay(1000);

			message_buffer.clear();
			
			smsFormatter.makeAlertSms('W', 'G', &location, isBatteryCharging, deviceBatteryLevel, bikeBatteryLevel);
			sim800L.send(SERVER_PHONE_NUMBER, smsFormatter.getStorage());
			sim800L.smartRead("+CMGS", 5, 1000);
			delay(100);



			message_buffer.clear();
		}
	}
	if (bikeFallen && fallTime == 0)
	{
		gyro_x = 0;
		gyro_y = 0;
		fallTime = millis();
		message_buffer.clear();

		strcpy_P(message_buffer.getStorage(), (char *)pgm_read_word(&(string_table[indexStringFallDetected])));
		sim800L.send(userPhoneNumber, smsFormatter.getStorage());
		delay(100);
		Serial.println(smsFormatter.getStorage());

		message_buffer.clear();
	}

	if (bikeFallen && millis() - fallTime >= FALL_CALL_TIMEOUT) // If the bike has fallen && user didn't respond in FALL_CALL_TIMEOUT miliseconds
	{
		gyro_x = 0;
		gyro_y = 0;
		bikeFallen = false;
		fallTime = 0;
		smsFormatter.makeAlertSms('W', 'F', &location, isBatteryCharging, deviceBatteryLevel, bikeBatteryLevel);
		sim800L.send(SERVER_PHONE_NUMBER, smsFormatter.getStorage());
		delay(500);

		/* TODO alert the user that we called is contacts */
	}

	if (!bikeFallen && millis() - lastHeartbeatTime >= HEARTBEAT_TIMEOUT ) // if it has beed heartbeat_timeout time since last heart beat sms send
	{
		lastHeartbeatTime = millis();
		if(journey)
		{
			int gyro_int_y = gyro_y;
			Serial.println("gyro_int_y before print --------------");
			Serial.println(gyro_int_y);
			Serial.println("--------------------");
			smsFormatter.makeJourneySms('@', &location, isBatteryCharging, deviceBatteryLevel, bikeBatteryLevel, bikeSpeed, gyro_int_y);
			Serial.println("smsFormatter.getStorage()");
			Serial.println(smsFormatter.getStorage());
			sim800L.send(SERVER_PHONE_NUMBER, smsFormatter.getStorage());
			sim800L.smartRead("+CMGS", 5, 500);
			delay(500);
		}else
		{
			smsFormatter.makeHeartbeatSms('*', &location, isBatteryCharging, deviceBatteryLevel, bikeBatteryLevel);
			Serial.println("smsFormatter.getStorage()");
			Serial.println(smsFormatter.getStorage());
			sim800L.send(SERVER_PHONE_NUMBER, smsFormatter.getStorage());
			sim800L.smartRead("+CMGS", 5, 500);
			delay(500);
		}
	}
	Serial.println("gyro ---------------");
	Serial.println("gyro_x");
	Serial.println(gyro_x);
	Serial.println("gyro_y");
	Serial.println(gyro_y);

	Serial.println("pos ----------------");
	Serial.println("latitude");
	printFloat(location.latitude , 1, 12, 6);
	Serial.println();
	Serial.println("longitude");
	printFloat(location.longitude , 1, 12, 6);
	Serial.println();

	Serial.println("speed --------------");
	Serial.println(bikeSpeed);
	Serial.println("--------------------");

	smartDelay(2000);
	readIncommingSms();

	/*smsFormatter.makeJourneySms('@', &location, isBatteryCharging, deviceBatteryLevel, bikeBatteryLevel, bikeSpeed, 40);
	Serial.println("smsFormatter.getStorage()");
	Serial.println(smsFormatter.getStorage());*/
	//delay(2000);
}

static void smartDelay(unsigned long ms)
{
	gpsSerial.listen();
	unsigned long start = millis();
	do
	{
		while (gpsSerial.available())
			gps.encode(gpsSerial.read());
	} while (millis() - start < ms);
	sim800L.listen();
}

static void printFloat(float val, bool valid, int len, int prec)
{
	if (!valid)
	{
		while (len-- > 1)
			Serial.print('*');
		Serial.print(' ');
	}
	else
	{
		Serial.print(val, prec);
		int vi = abs((int)val);
		int flen = prec + (val < 0.0 ? 2 : 1); // . and -
		flen += vi >= 1000 ? 4 : vi >= 100 ? 3
							 : vi >= 10	   ? 2
										   : 1;
		for (int i = flen; i < len; ++i)
			Serial.print(' ');
	}
	delay(0);
}

void readIncommingSms()
{
	if (sms_buffer.indexOf("+CMTI", 5) != -1)
	{
		Serial.println("sms_buffer.getStorage()");
		Serial.println(sms_buffer.getStorage());
		treatSMS();
		return;
	}
	sim800L.carriageReturn();

	sim800L.deleteALLRead();
	sim800L.carriageReturn();
	sim800L.setModeTexte();
	sim800L.carriageReturn();

	if (sim800L.smartRead("+CMGR", 5, 1000))
	{
		//if (sms_buffer.indexOf("+CMTI", 5) != -1)
		//{
			Serial.println("sim800L.smartRead(, 5, 1000)");
			Serial.println(sms_buffer.getStorage());
			sim800L.setModeTexte();
			sim800L.carriageReturn();
			sim800L.smartRead("+CMTI", 5, 1000);
			Serial.println(sms_buffer.getStorage());
			treatSMS();
		//}
	}
}

void actualizeLocation()
{
	//noInterrupts();
	gpsSerial.listen();

	if (location.latitude - gps.location.lat() >= GPS_TRESHOLD_LAT ||
		location.latitude - gps.location.lat() <= -GPS_TRESHOLD_LAT ||
		location.longitude - gps.location.lng() >= GPS_TRESHOLD_LON ||
		location.longitude - gps.location.lng() <= -GPS_TRESHOLD_LON) // Calcul delta pos
	{
		bikeMoved = true;
	}
	location.latitude = gps.location.lat();
	location.longitude = gps.location.lng();
	bikeSpeed = gps.speed.kmph();
	sim800L.listen();
	//interrupts();
}

void actualizeBatterys()
{
	deviceBatteryLevel = 42;//(analogRead(A3)/deviceMaxBatteryVoltage*100);
	bikeBatteryLevel = 69;//(analogRead(A3)/bikeMaxBatteryVoltage*100);
}

void actualizeIsBatteryCharging()
{
	isBatteryCharging = false;
}

void actualizeAngle()
{
	Wire.beginTransmission(MPU_ADDR);
	Wire.write(0x3B);

	Wire.endTransmission(false);
	Wire.requestFrom(MPU_ADDR, 2 * 2, true);

	gyro_y = Wire.read() << 8 | Wire.read();
	gyro_x = Wire.read() << 8 | Wire.read();

	if (zeroGyro_y == 0 || zeroGyro_x == 0)
	{
		zeroGyro_y = gyro_y;
		zeroGyro_x = gyro_x;
	}
	gyro_x = (gyro_x - zeroGyro_x) / GYRO_MIN_MAX_X * 90;
	gyro_y = (gyro_y - zeroGyro_y) / GYRO_MIN_MAX_Y * 90;


	if (fallTime == 0 && 
		//gyro_x >= ANGLE_TRESHOLD ||
		//gyro_x <= -ANGLE_TRESHOLD ||
		gyro_y >= ANGLE_TRESHOLD ||
		gyro_y <= -ANGLE_TRESHOLD)
	{
		bikeFallen = true;
	}
	Wire.endTransmission(true);
}

void vibartionDetected()
{
	vibartion = true;
}

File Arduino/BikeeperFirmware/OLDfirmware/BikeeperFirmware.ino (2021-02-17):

/*
for the arduino uno
                                             ╔═══╗                   ╔═════╗
                                        ╔════╣PWR╠═══════════════════╣ USB ╠══╗
                                        ║    ╚═══╝                   ╚═════╝  ║
                                        ║         GND/RST2  [ ][ ]            ║
                                        ║       MOSI2/SCK2  [ ][ ]  A5/SCL[ ] ║ 
                                        ║          5V/MISO2 [ ][ ]  A4/SDA[ ] ║
                                        ║                             AREF[ ] ║
                                        ║                              GND[ ] ║
                                        ║ [ ]N/C                    SCK/13[ ] ║
                                        ║ [ ]IOREF                 MISO/12[ ] ║
                                        ║ [ ]RESET                 MOSI/11[ ]~║
                                        ║ [ ]3V3    ╔═══╗               10[ ]~║
  +5V (2A) external power supply <══════║ [ ]5v    ═╣ A ╠═               9[ ]~║
    Ground external power supply <══════║ [ ]GND   ═╣ R ╠═               8[ ] ║══════> SIM800L rx 
                                        ║ [ ]GND   ═╣ D ╠═                    ║
                                        ║ [ ]Vin   ═╣ U ╠═               7[ ] ║══════> SIM800L tx
                                        ║          ═╣ I ╠═               6[ ]~║
                                        ║ [ ]A0    ═╣ N ╠═               5[ ]~║
                                        ║ [ ]A1    ═╣ O ╠═               4[ ] ║══════> GPS tx
                                        ║ [ ]A2     ╚═══╝           INT1/3[ ]~║
                                        ║ [ ]A3                     INT0/2[ ] ║══════> Interrupt pin for the "do" pin of the vibration sensor
                                        ║ [ ]A4/SDA  RST SCK MISO     TX>1[ ] ║
                                        ║ [ ]A5/SCL  [ ] [ ] [ ]      RX<0[ ] ║
                                        ║            [ ] [ ] [ ]              ║
                                        ║            GND MOSI 5V ╔════════════╝
                                        ╚═══UNO_R3═══════════════╝ 
*/
#include "Headers/messageHeader.h"
#include "Headers/messageAlert.h"
#include "Headers/messageTrajet.h"
#include "Headers/messageHeartbeat.h"
#include "Headers/messageReceived.h"
#include "Headers/location.h"

#include <TinyGPS++.h>

//Server
#define SERVER_PHONE_NUMBER "+33769342048"  // BiKServer number (main server) called to get user number

//SIM 800L
#include <SoftwareSerial.h>                 // need to be slightly modified to have a bigger buffer (100 instead of 64)
                                            // line 43 #define _SS_MAX_RX_BUFF 64
                                            // will become #define _SS_MAX_RX_BUFF 100
String userPhoneNumber;                     // Device owner phone number TODO make it changable in the setup call SERVER_PHONE_NUMBER to get phone number
#define GSM_BAUDRATE 9600			        // Works because the sim800l baud rate is "hard coded" in the module.
#define GSM_RX 7					        // Declare the SIM800L onto the pin 7.
#define GSM_TX 8					        // Declare the SIM800L onto the pin 8.
#define STR_LENGTH 160				        // SMS lenght max 160 (one sms in limited in size !).

SoftwareSerial sim800l(GSM_RX, GSM_TX);     // Declare the SIM800L onto the pins 7, 8.

String answer, SMS;
String senderPhoneNumber;
unsigned long t0;



//Vibration sensor
bool vibartion = false;                     // False most of the time but true if the module detected a vibration (trough interrupt)

#define VIBRATION 'V'

//Battery sensor
#define DEVICE_BATTERY_PIN  0               // Declare the device battery (analog)
#define BIKE_BATTERY_PIN  1	                // Declare the device battery (analog)

int deviceBatteryLevel = 0;
int bikeBatteryLevel = 0;

bool isBatteryCharging = false;


//State

bool parked = false;
bool journey = false;

//GPS
#define GPS_RX 4					        // Declare the SIM800L onto the pin 7.
#define GPS_TX 3	

#define GPS_BAUDRATE 9600
TinyGPSPlus gps;

location_t location;		                // Declare the Location type
SoftwareSerial gpsSerial(GPS_RX, GPS_TX);

void setup()
{
    Serial.begin(9600);

    //GPS 
    gpsSerial.begin(GPS_BAUDRATE);
    
	//SIM 800L
	sim800l.begin(9600);
    
    
    sim800l.listen();
	//Vibration sensor
	attachInterrupt(0, vibartionDetected, RISING); // Interrupt for the vibration detector (RISING because the detector emmit ~3.5V for 10 ms).
  
  initCard();
  LireSMS();                                                  // Si nouveau SMS disponible SIM800 envoie +CMTI:
    sim800l.println("AT+CMGD=1,2");
	message("OK", 1000, 0);
	sim800l.println("AT+CMGDA=DEL INBOX");
    message("OK", 1000, 0); 
}

static void smartDelay(unsigned long ms)
{
  gpsSerial.listen();
  unsigned long start = millis();
  do 
  {
    while (gpsSerial.available())
      gps.encode(gpsSerial.read());
  } while (millis() - start < ms);
  sim800l.listen();

}
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

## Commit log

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2020-11-29 🔨[ADD] Starting SMS Emulator
    Allow user to generate fake messages using our custom protocols
2021-01-11 ➕[ADD] Arduino Snippets(SMS & vibration)
    [Vibration_detector.ino, sms_sender.ino]
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2021-01-11 📦[ADD] Work on osm server and flask mobile
    - Setup osm server map using Docker
    - Detect phone using Flask-Mobility
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2021-01-11 Update structure
    avec une maj de ce que j'ai fait
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2021-01-11 ✨Implémentation de l'ORM et liaison de MariaDB
    Ajout de la configuration de MariaDB ainsi que de l'ORM dans le fichier app.py
    Implémentation des classes de l'ORM ainsi que de quelques fonctions basiques permettant d'avoir une structure de base
    Implémentation de routes afin de tester l'ORM
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2021-01-11 ➕[ADD] Connexion system
    Update BD : password, profile picture
2021-01-11 ♻️Refactoring the code of the ORM
    Updating class ORM with functions related to the register/login functions of the view + modifying insert file
2021-01-11 ➕ [ADD] settings.html PC
    Quick fixes on CSS
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2021-01-11 ➕ [ADD] Account page PC
    Fix url_for
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2021-01-12 ➕ [ADD] Device Page PC
    Sidebar --> transform CSS
    Scrollbar --> CSS
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2021-01-12 ➕ [ADD] Contacts page PC
    Contact Edit/Remove/Add template
2021-01-12 🎨 [CSS] quick fix
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2021-01-12 ➕🎨 [ADD/CSS] Add subscription & fix a tons of css
2021-01-13 [FIX] database hash insert
    And add arduino server test file
    [server.py]
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2021-01-13 Modification de routes certain fichier + implementation 3 pages user
    statistic, support et localisation, n'utilise pas encore la BD
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2021-01-13 ➕ [ADD] Stats Page PC
    TONS OF CSS
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2021-01-13 ✨ Introducing some exemple files in order to communicate with the server
2021-01-13 ➕ [ADD] js input file and quick css
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2021-01-14 🚀🔀Merged sippets together & more 🚧
    ✔️SMS char array formatter
    ✔️SMS Structs (optimized) & easier full message generation
    ✔️Send SMS optimized (fastest)
    ✔️SMS protocole optimized
    ✔️Angle detection (need to convert to usefull data)
    ✔️Divides .ino file (easier to read)
    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
2021-01-15 ♻️ Modifying serverino
    the arduino server is now properly working to send/receive from ORM/Client arduino
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2021-01-15 🐛 Fixing bugs and adjusting python with arduino
    [AlertSendProtocol.py, PositionTrajetProtocol.py, server.ino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]
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2021-01-15 ✨ Added ORM methods to create and commit objects in the database
2021-01-15 ✨ Writing an example of an API function
    this function will receive data from the python files that himself receive data from the arduino server, and treat those information to store them in the database.
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2021-01-18 🌐 [ADD] Api send and receive data
    Create useful functions to deal with API more easily
2021-01-18 🩹[FIX] requirements and app server IP
2021-01-20 🔀 [EDIT] Refactoring data import
    Now using yaml file to store data
    Edit database to implement admin IP graph
2021-01-21 📝[ADD] Map view in localisation mobile
    And refactoring nav side bar
    Now it use components
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2021-02-06 ✨ Adding error function + remove_bikeeper to the API
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2021-02-06 🐛 Fixing ORM add functions
2021-02-06 🐛 Fixing API functions
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2021-02-11 🎉 added Gps Location to the firmware
    May need refactoring 🚨 memory limitation !!!
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2021-02-14 🔧 [FIX] Some mistakes on file names
    There were some conflicts between pc and mobile file names for account.html
2021-02-14 Changement des noms
    noms des fichiers, des éléments des forms et de base + les différentes pages html pour avoir un css correct
2021-02-14 tentative de changement de profile
    test de changement de profile non concluant + quelques améliorations
2021-02-14 Changement des liens
    Les liens d'overlay et d'accès à la page ont était changé
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2021-02-14 🎉Fixed buffers bug 🐛 dur to memory usage
    optimized memory used by strings & library
    💥Light sms library will be needed for memory & comprehension
    [BikeeperFirmware.ino, StringsSms.ino, init.ino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]
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2021-02-15 🐛 Fixing bugs on the send_sms_bd + add new functions
2021-02-15 🐛 Fixing Datetime format + add get_contacts function
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2021-02-15 🔧 [FIX] header & sidebar links to url_for
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2021-02-15 ♻️ Refactoring the python arduino code
    modifiying boolean types to strings + using requests in server.py
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2021-02-15 ♻️ Adding the name of the bikeeper owners in the response of get_contact
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2021-02-15 ✨ Adding Alert_Fall function in order to send sms to the contacts
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2021-02-16 🔧 [FIX] Register patterns
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2021-02-16 🎉Fixed🐛Bug user phone number
    [I_Sim800L.cpp]
2021-02-16 ✨ Adding get_ride function that gets a specific ride
    ♻️ also refactoring the function to get rides to return json instead of python objects in order to pass them to JS
2021-02-16 ✨ Adding a variable to get the ride and send it to the JS
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2021-02-16 🔥 Removing useless Jinja variables as this will be gathered with the API
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2021-02-16 [CSS] 🎨 Quick CSS fixes on home.css
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2021-02-17 🎉🎉Firmware optimisation Good
    💡 If possible or needed create state pattern
    🔨 some AT commands need to be functionalized
    🔥 remove OLD unoptimized code
2021-02-17 🎉✨Optimized GPS, Interrupt, SMS, memory @ 48% (✨1000✨o)
    🚨 Optimisation may end soon 🚀
    🔨 Still AT commands to check
2021-02-17 🔨 [FIX] support feature on profile picture
2021-02-17 ✨ Adding a function to display tracks on the map
    🎨 Moved the js in a actual js file 🤡
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2021-02-17 ✨ Sending log to the API when the arduino server receive a fall message
2021-02-17 🗃 [BD] Add Subscription Class & update USER
    USER :
    --> is_account_blocked
    --> date_creation_user
    --> name_subscription
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2021-02-17 🐛 Fixing Timeline issues
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2021-02-17 ✨ Adding ids for fields i'll need to modify in the JS
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2021-02-17 ✨ Adding id to the field that displays the battery level and charge
2021-02-17 ✨ Adding function to gather battery data to the ORM and the API
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2021-02-17 ✅[FIX] unit test
2021-02-18 🩹 [FIX] devices missing in stats.py
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2021-02-18 🚀[ADD] Image upload and update account on mobile
    Need do finish this feature when clicking on update
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2021-02-18 🩹 [FIX] User block account
    A user could be unblocked even if he left the platform
2021-02-19 🩹 [FIX] routing login.login in app.py
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2021-02-19 💄 [FIX] display
2021-02-19 🩹 [ADD] Fix map localisation mobile
2021-02-19 🩹 [FIX] mobile sidebar guest & url_for
2021-02-19 ⚡Updated treat sms & functions
    - Added logs for every actions performed by the user
    - Added UI strings
    - Updated device <==> server magic
    - Reimplemented beginning of the device main logic
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2021-02-19 💄 [CSS] Quick fixes
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2021-02-20 🩹[FIX] CSS and url_for
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2021-02-20 Update overlay
    note : le modele avait des problemes d'indentation de mon cotes donc j'ai converti les spaces en tabs (ou l'inverse je sais plus)
2021-02-27 👷⬆️🔧🚧[ADD] Docker compose file , and remove bad paterns in HTML
    Need to find new patterns for forms validation register
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2021-03-03 🩹 [FIX] CSS & questions syntax
2021-03-03 🐛 Fixing bugs in python arduino code
    fixed a route, fixed fall message encoding and fixed data used in alrt_fall function
    [sendtrajet.py, server.py]
2021-03-03 🐛 Fix a bug with NoneType objects
2021-03-03 🐛 Fixing return if no last position
2021-03-03 🐛 Fixing battery img not loading
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2021-03-05 ✨Angle & Fall detection logic
    ⚡Updated sms treatement to add a "fine" command in case of a false fall detection to prevent calling user contatcs uselessly
    ⚡Added fall detection logic
    [BikeeperFirmware.ino, angle.ino, smsTreatment.ino]
2021-03-05 ⚡Heartbeat sms /!\ angle not working very well
    [BikeeperFirmware.ino, I_Sim800L.cpp, smsTreatment.ino]
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2021-03-07 🩹[FIX] CSS
2021-03-07 🩹[FIX] PC Titles
2021-03-07 🩹[FIX] Mobile titles
2021-03-07 🩹[FIX] CSS stats : map
2021-03-09 🚧 Implementing contact upload image
    TODO : remove prints and imporve js to replace image dynamically
    [utils.py]
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2021-03-13 🩹 [FIX] bugs discovered by Mathieu
2021-03-13 🩹 [FIX] Sidebar request referrer
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2021-03-13 🐛 [FIX] Solve ticket that doesn't delete correclty
2021-03-13 🩹 [FIX] support indentation & dupplication
2021-03-13 🩹 [FIX] support TypeError (no active link)
2021-03-13 🩹 [FIX] Dupplication of bin icon
2021-03-13 🩹 [FIX] support close tickets
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2021-03-13 🐛 [FIX] Reverse proxy
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2021-03-13 🚑 [FIX] Reverse proxy forwarded IP
2021-03-15 💄 [CSS] Fix support align-center ticket
2021-03-16 🐛 Fixing bugs concerning interaction between server and device
    [sendtrajet.py, server.py]
2021-03-16 🩹 [FIX] Fix data.yml number of device
2021-03-16 [ADD] 4 questions & Delete 1 duplicates
    Ajout des 4 dernières questions et suppression d'un doublons concernant le support(bug)
2021-03-16 🩹[FIX] Fix stats css & admin cards
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2021-03-16 🐛 [EDIT] Put env variables in app
    In prod flask doesn't see .flaskenv variables....
    [sendtrajet.py]
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2021-03-17 🐛[FIX] hard navigation
    Admin cannot reach user page anymore
    Conected users cannot reach unlogged page anymore
2021-03-17 🩹[FIX] Support change ticket
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2021-03-18 🐛[FIX] Mobile support
2021-03-18 ➕Added Arduino Nano 3D model
    [Arduino_Nano.SLDPRT]
2021-03-18 ➕Added Arduino Charger 3D model
    [Chargeur_Li-ion.SLDPRT]
2021-03-18 ➕Added Arduino Tilt Sensor 3D model
    [Tilt_Sensor.SLDPRT]
2021-03-18 ➕Added Arduino Vibration detector 3D model
    [Vibration_detector.SLDPRT]
2021-03-18 ➕Added Arduino SIM 800L 3D model
    [SIM_800L.SLDPRT]
2021-03-18 ➕Added Arduino GPS 3D model
    [GPS.SLDPRT]
2021-03-18 🐛[FIX] speed glitch + 3d models
    [Arduino_Nano.SLDPRT, Batterie.SLDPRT, Box_Bottom.SLDPRT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]
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2021-03-18 [FIX] Contact link to device
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2021-03-19 🐛[FIX] Critical bug missed db. before session
2021-03-19 🐛 [FIX] Bugs in database model not ended transactions.
